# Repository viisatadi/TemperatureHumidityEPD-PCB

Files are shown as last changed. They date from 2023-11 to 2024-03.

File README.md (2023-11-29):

Temperature/Humidity ePaper Display KiCad Files
===============================================
  
This project is an attempt to port Kevin Kessler's Hackaday project from an STM32L0 MCU to one from Analog Devices. The purpose of this project was to investigate the effort required to switch micros.

From the original repo:
In order to investigate the low power modes and techniques for an STM32L0 class microprocessor, I've build a temperature and humidity display using an STM32L031F6 uC, an SI7021 I2C temperature/humidity sensor, and a Waveshare 1.54 inch black, white, and red ePaperDisplay. Starting with a straight-forward, non-optimized version of the software, this project will investigate and document the various power savings techniques that can be applied to the system, in order to get the power usage of the device down to a level that (hopefully) makes it practical to run off of a CR2032 coin cell. 

Track the progress on [Hackaday.io](https://hackaday.io/project/134018-coin-cell-powered-temperaturehumidity-display)

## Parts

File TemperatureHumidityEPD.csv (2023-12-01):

Reference | Value | Footprint | Datasheet | Description | Part Number | Qty
BT1 | CR2032 | Connectors_Custom:BatteryHolder_TE_BATT-HLD-000_1x2032 | ~ |  | BAT-HLD-001 | 1
C1, C10, C11, C14-C20 | 10u | Capacitor_SMD:C_0603_1608Metric_Pad1.08x0.95mm_HandSolder |  | capacitor, 10u, 10%, 10V, ceramic, X7T, SMT, 0603 (1608) | GRM188D71A106KA73J | 10
C2, C4, C5, C13 | 1u | Capacitor_SMD:C_0603_1608Metric_Pad1.08x0.95mm_HandSolder | ~ | capacitor, 1u, 10%, 10V, ceramic, X7R, SMT, 0603 (1608) | C1608X7R1A105K080AC | 4
C3 | 100n | Capacitor_SMD:C_0603_1608Metric_Pad1.08x0.95mm_HandSolder |  | capacitor, 0.1u, 5%, 16V, ceramic, X7R, SMT, 0603 (1608) | C0603C104K3RACTU | 1
C6, C8 | 22u | Capacitor_SMD:C_1206_3216Metric_Pad1.33x1.80mm_HandSolder |  | capacitor, 22u, 10%, 6.3V, ceramic, X7R, SMT, 1206 | GRM31CR70J226KE19L | 2
C7 | 22p | Capacitor_SMD:C_0603_1608Metric_Pad1.08x0.95mm_HandSolder |  | capacitor, 22p, 5%, 50V, ceramic, C0G, SMT, 0603 (1608) | CC0603JRNPO9BN220 | 1
C9, C12 | 4.7u | Capacitor_SMD:C_0805_2012Metric_Pad1.18x1.45mm_HandSolder |  | capacitor, 4.7u, 10%, 25V, ceramic, X7S, SMT, 0805 (2012) | GRM21BC71E475KE11L | 2
D1, D2 | LED | LED_SMD:LED_0805_2012Metric_Pad1.15x1.40mm_HandSolder | https://www.mouser.com/datasheet/2/180/IN_S85AT_Series_V1_1-2323391.pdf | LED, white, SMT, 0805 (2012) | IN-S85AT5UW | 2
D3-D5 | MBR0530 | Diode_SMD:D_SOD-123 | http://www.mccsemi.com/up_pdf/MBR0520~MBR0580(SOD123).pdf | diode, Schottky, 30Vr, 0.5A, SMT, SOD-123-3 | MBR0530T1G | 3
J1 | Conn_01x02 | Connectors_Custom:Pin_Header_Straight_1x02_Pitch2.54mm |  |  |  | 1
J2 | FTSH-105-01-L-DV-K | Connectors_Custom:SAMTEC_FTSH-105-01-L-DV-K | https://suddendocs.samtec.com/prints/ftsh-1xx-xx-xxx-dv-xxx-xxx-x-xx-mkt.pdf | connector, 10-pin, 2x5, 0.5mm pitch, polarized, SMT | FTSH-105-01-L-DV-K | 1
J3 | Conn_01x08 | Connector_JST:JST_PH_S8B-PH-SM4-TB_1x08-1MP_P2.00mm_Horizontal | https://www.jst-mfg.com/product/pdf/eng/ePH.pdf |  |  | 1
J4 | Conn_01x24 | Connectors_Custom:TE_2-1734839-4_1x24-1MP_P0.5mm_Horizontal_reversednumber | https://www.mouser.com/datasheet/2/418/7/ENG_CD_1734839_C_C_1734839-2017341.pdf | connector, FPC, 24 pin, 0.5mm pitch, top contact | 2-1734839-4 | 1
L1, L3 | 0 | Resistor_SMD:R_0603_1608Metric_Pad0.98x0.95mm_HandSolder |  | resistor, 0, 0.25W, thick film, SMT, 0603 (1608) | RCS06030000Z0EC | 2
L2 | 1u | Inductors_Custom:L_0805_2016Metric | https://product.tdk.com/system/files/dam/doc/product/inductor/inductor/smd/catalog/inductor_commercial_power_mlp2016_en.pdf | inductor, 1u, 20%, 1A, 117mohm, SMD, 0806 (2016) | MLP2016S1R0MT0S1 | 1
L4 | 68u | Inductors_Custom:L_3x3_H3 | https://www.bourns.com/pdfs/SDR0302.pdf | inductor, 68u, 10%, 300mA, 1.85ohm, SMT, 3mm_diam x 2mm | SDR0302-680KL | 1
MP1-MP4 | MOUNTHOLE | Connectors_Custom:TH-M3 |  |  |  | 4
Q1 | Si1308EDL | Package_TO_SOT_SMD:SOT-323_SC-70 | https://www.vishay.com/doc?63399 | mosfet, n-ch, 30V, 1.5A, 132mohm, 600mVth, SOT-323-3 (SC-70) | Si1308EDL-T1-GE3 | 1
Q2 | IRLML6344 | Package_TO_SOT_SMD:SOT-23-3 |  | mosfet, n-ch, 30Vds, 5A, 29mohm, 800mVth, SOT-23-3 | IRLML6344TRPBF | 1
R1-R5, R15, R19 | 10K | Resistor_SMD:R_0603_1608Metric_Pad0.98x0.95mm_HandSolder |  | resistor, 10k, 0.1W, thin film, 1%, 50ppm, SMT, 0603 (1603) | RT0603FRE0710KL | 7
R6, R7 | 1k | Resistor_SMD:R_0603_1608Metric_Pad0.98x0.95mm_HandSolder |  | resistor, 1k, 0.1W, thin film, 1%, 50ppm, SMT, 0603 (1608) | RT0603FRE131KL | 2
R8, R16 | 100R | Resistor_SMD:R_0603_1608Metric_Pad0.98x0.95mm_HandSolder |  | resistor, 100, 0.1W, thin film, 1%, 50ppm, SMT, 0603 (1603) | RT0603FRE07100RL | 2
R9, R10, R14 | 0 | Resistor_SMD:R_0603_1608Metric_Pad0.98x0.95mm_HandSolder |  | resistor, 0, 0.25W, thick film, SMT, 0603 (1608) | RCS06030000Z0EC | 3
R11, R12 | 56 | Resistor_SMD:R_0603_1608Metric_Pad0.98x0.95mm_HandSolder |  | resistor, 56, 0.1W, thick film, 1%, SMT, 0603 (1608) | RC0603FR-0756RL | 2
R13 | DNP | Resistor_SMD:R_0603_1608Metric_Pad0.98x0.95mm_HandSolder |  | resistor, 0, 0.25W, thick film, SMT, 0603 (1608) | RCS06030000Z0EC | 1
R17 | 100K | Resistor_SMD:R_0603_1608Metric_Pad0.98x0.95mm_HandSolder |  | resistor, 100k, 0.1W, thin film, 1%, 50ppm, SMT, 0603 (1603) | RT0603FRE07100KL | 1
R18 | 0R47 | Resistor_SMD:R_0805_2012Metric_Pad1.20x1.40mm_HandSolder |  | resistor, 0.47, 0.25W, thin film, 5%, 300ppm, SMT, 0805 (2012) | 2-2176054-4 | 1
SW1 | SW_Push | Switch_Custom:Panasonic_EVQPUJ_EVQPUA | ~ | switch, momentary-off, SMT | EVQ-P7A01P | 1
TP1, TP2 | TestPoint_2Pole | Connectors_Custom:TestPoint_Padx2_D2.0mm |  |  |  | 2
U1 | SI7021 | Silabs_custom:SI7021 | https://www.silabs.com/documents/public/data-sheets/Si7021-A20.pdf | IC, temperature and humidity sensor, SMT, DFN6_3x3 | SI7021-A20-GM1 | 1
U2 | MAX32660GTP | Package_DFN_QFN:TQFN-20-1EP_4x4mm_P0.5mm_EP2.7x2.7mm | https://www.analog.com/media/en/technical-documentation/data-sheets/max32660.pdf | IC, microcontroller, SMT, TQFN-EP-20 | MAX32660GTP | 1
U3 | MAX20343H | ADI_Power:MAX20343H | https://www.analog.com/media/en/technical-documentation/data-sheets/MAX20343-MAX20344.pdf | power regulator, buck-boost, 1.9V-5.5Vin, 3.5W, SMT, FC2QFN-12 | MAX20343HEFC+ | 1
Y1 | 32.7680KHZ | Crystal:Crystal_SMD_MicroCrystal_CM9V-T1A-2Pin_1.6x1.0mm_HandSoldering | ~ | crystal, 32.7680KHZ, 6PF, +/-20PPM, SMT, 1.6mm x 1.0mm | CM1610H32768DZB | 1

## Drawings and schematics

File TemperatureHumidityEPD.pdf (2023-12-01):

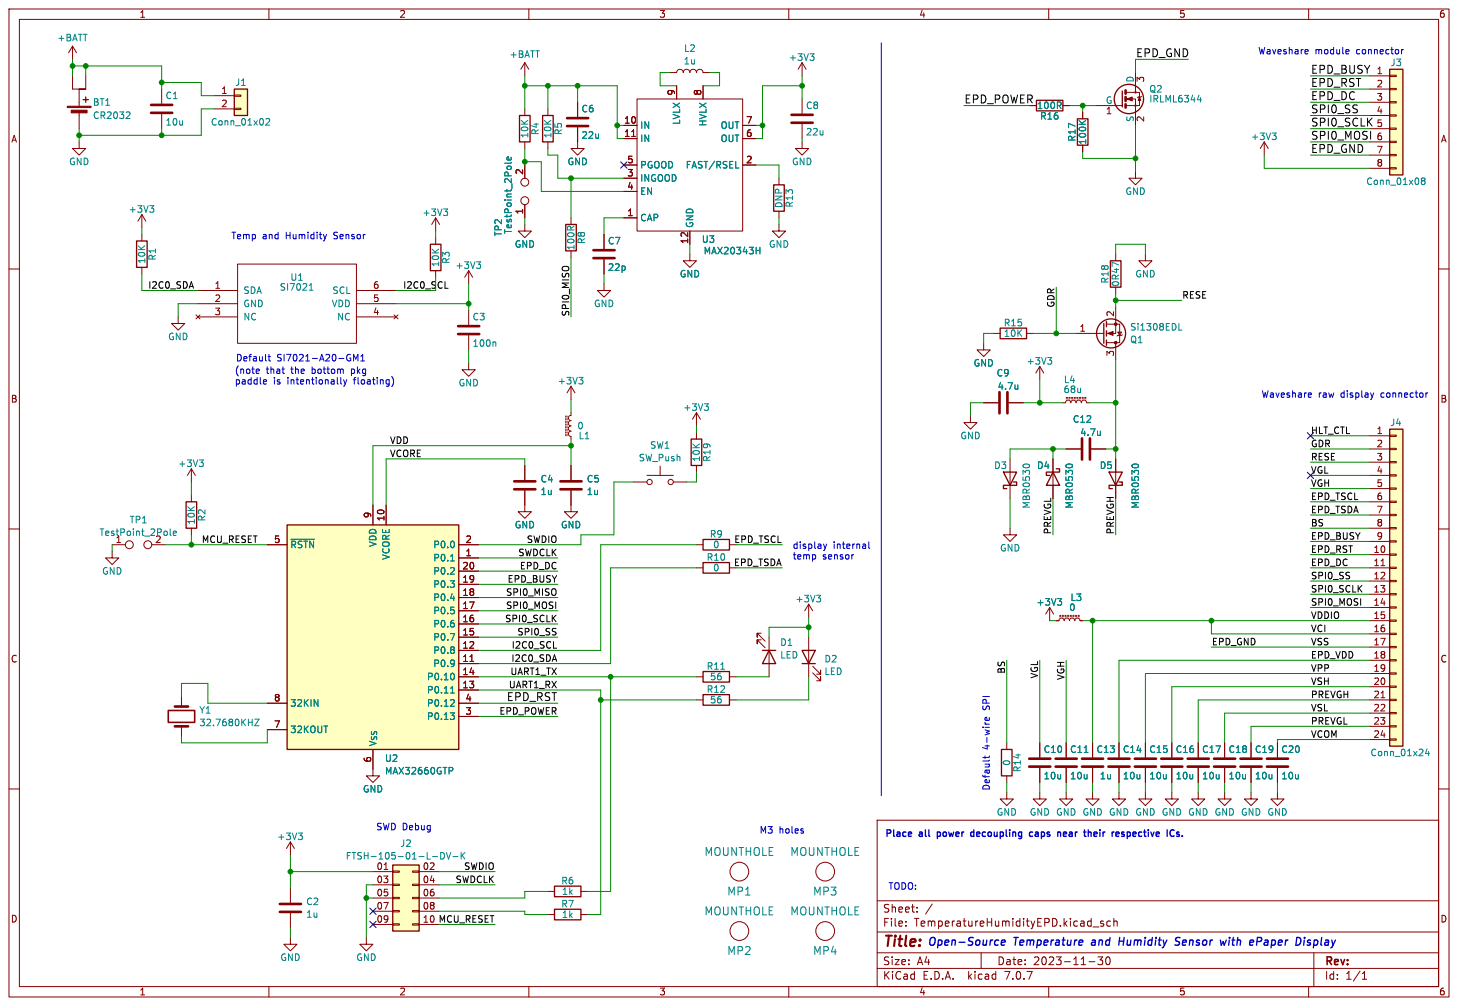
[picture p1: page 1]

(note that the bottom pkg

Id: 1/1 Title: File: TemperatureHumidityEPD.kicad_sch Sheet: /

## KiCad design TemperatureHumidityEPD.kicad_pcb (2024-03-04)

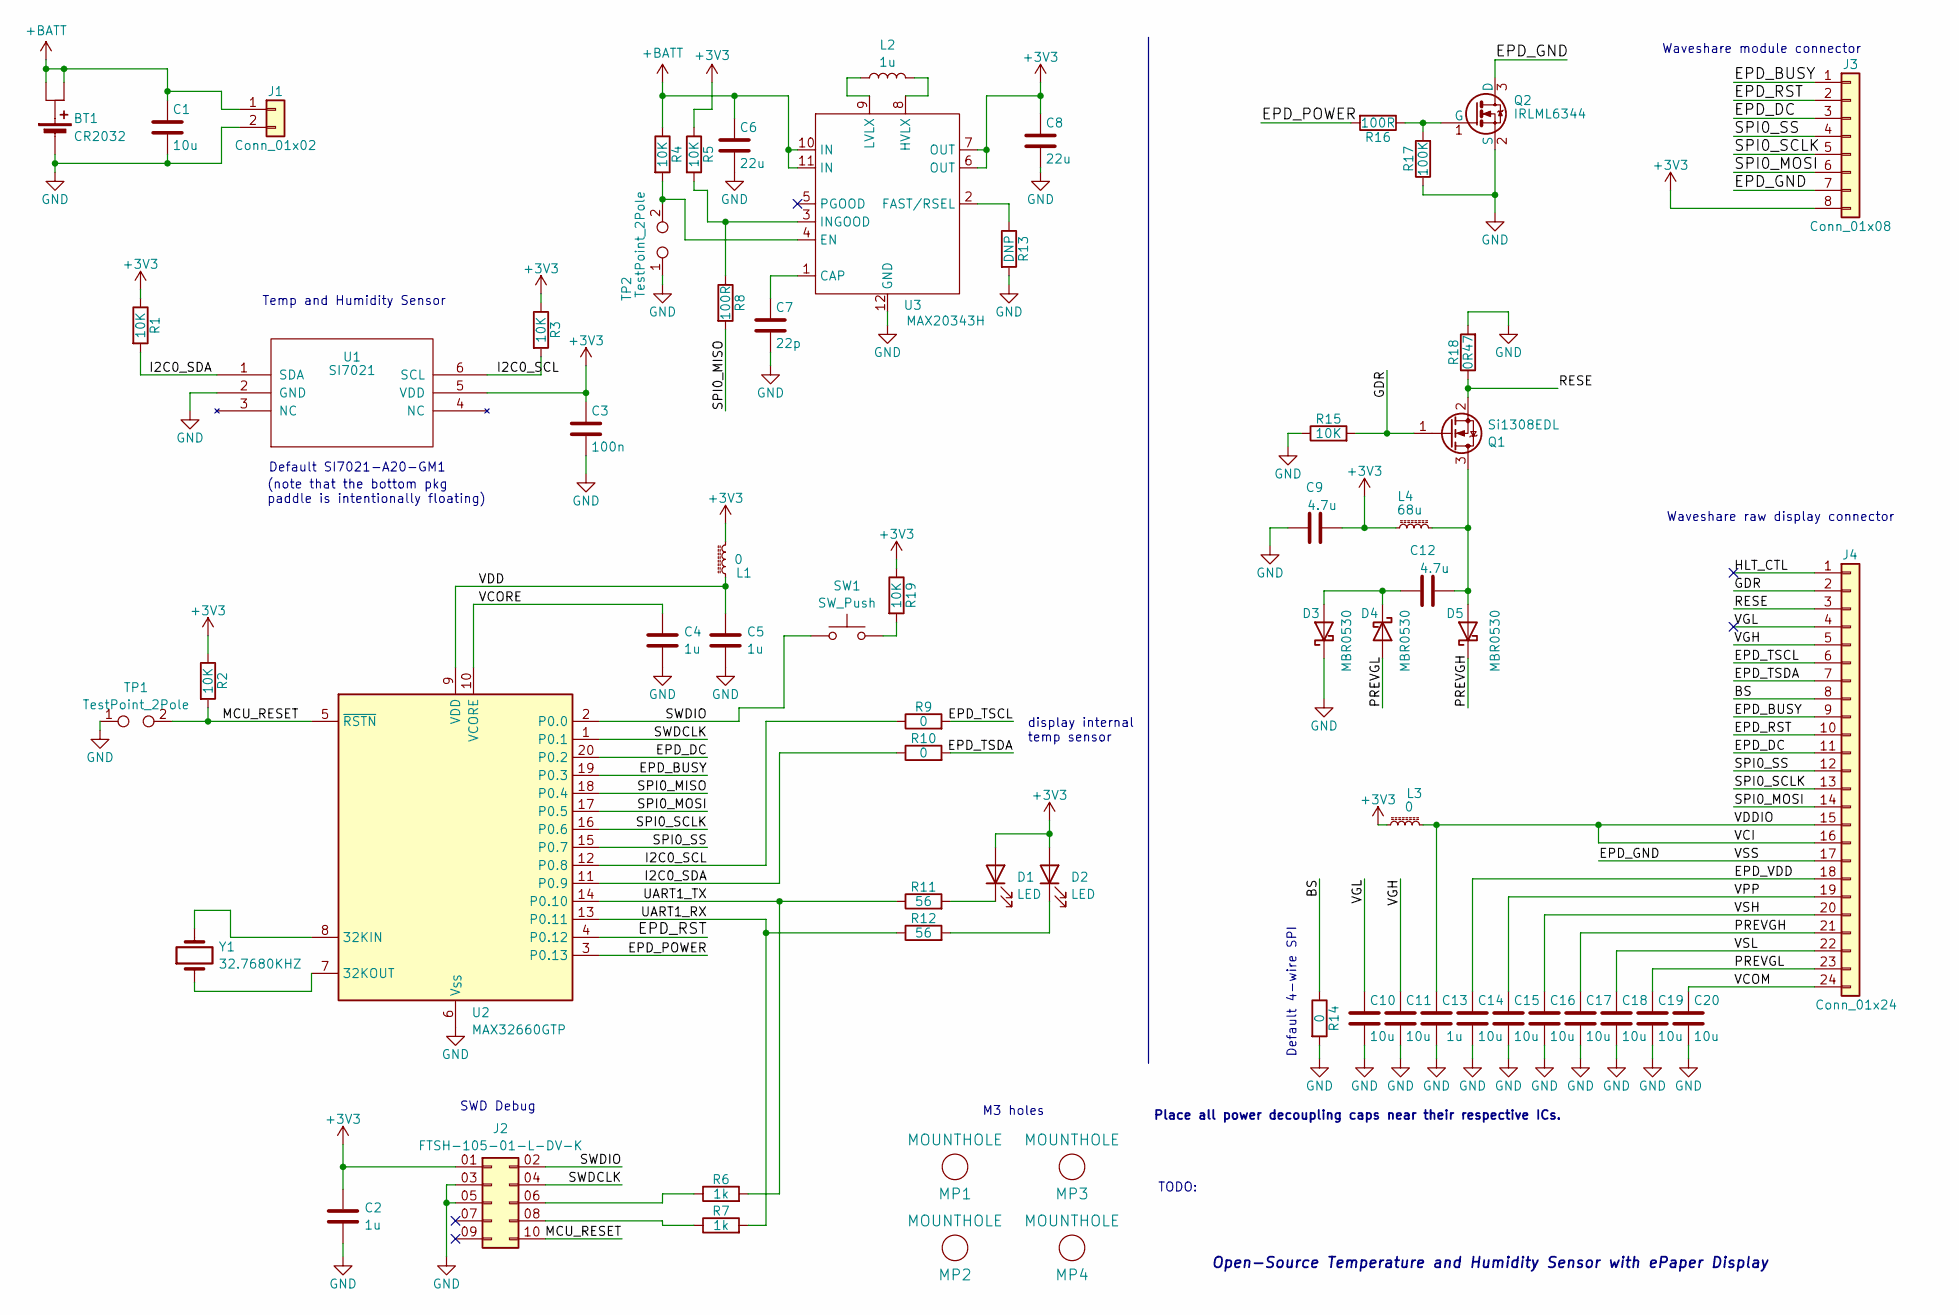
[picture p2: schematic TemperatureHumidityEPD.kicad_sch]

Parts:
BT1: CR2032; BatteryHolder_TE_BATT-HLD-000_1x2032; Part Number BAT-HLD-001
C1, C10, C11, C14, C15, C16, C17, C18, C19, C20: 10u; C_0603_1608Metric_Pad1.08x0.95mm_HandSolder; Part Number GRM188D71A106KA73J
C2, C4, C5, C13: 1u; C_0603_1608Metric_Pad1.08x0.95mm_HandSolder; Part Number C1608X7R1A105K080AC
C3: 100n; C_0603_1608Metric_Pad1.08x0.95mm_HandSolder; Part Number C0603C104K3RACTU
C6, C8: 22u; C_1206_3216Metric_Pad1.33x1.80mm_HandSolder; Part Number GRM31CR70J226KE19L
C7: 22p; C_0603_1608Metric_Pad1.08x0.95mm_HandSolder; Part Number CC0603JRNPO9BN220
C9, C12: 4.7u; C_0805_2012Metric_Pad1.18x1.45mm_HandSolder; Part Number GRM21BC71E475KE11L
D1, D2: LED; LED_0805_2012Metric_Pad1.15x1.40mm_HandSolder; Part Number IN-S85AT5UW
D3, D4, D5: MBR0530; D_SOD-123; Part Number MBR0530T1G
J1: Conn_01x02; Pin_Header_Straight_1x02_Pitch2.54mm
J2: FTSH-105-01-L-DV-K; SAMTEC_FTSH-105-01-L-DV-K; Part Number FTSH-105-01-L-DV-K
J3: Conn_01x08; JST_PH_S8B-PH-SM4-TB_1x08-1MP_P2.00mm_Horizontal
J4: Conn_01x24; TE_2-1734839-4_1x24-1MP_P0.5mm_Horizontal_reversednumber; Part Number 2-1734839-4
L1, L3: 0; R_0603_1608Metric_Pad0.98x0.95mm_HandSolder; Part Number RCS06030000Z0EC
L2: 1u; L_0805_2016Metric; Part Number MLP2016S1R0MT0S1
L4: 68u; L_3x3_H3; Part Number SDR0302-680KL
MP1, MP2, MP3, MP4: MOUNTHOLE; TH-M3
Q1: Si1308EDL; SOT-323_SC-70; Part Number Si1308EDL-T1-GE3
Q2: IRLML6344; SOT-23-3; Part Number IRLML6344TRPBF
R1, R2, R3, R4, R5, R15, R19: 10K; R_0603_1608Metric_Pad0.98x0.95mm_HandSolder; Part Number RT0603FRE0710KL
R6, R7: 1k; R_0603_1608Metric_Pad0.98x0.95mm_HandSolder; Part Number RT0603FRE131KL
R8, R16: 100R; R_0603_1608Metric_Pad0.98x0.95mm_HandSolder; Part Number RT0603FRE07100RL
R9, R10, R14: 0; R_0603_1608Metric_Pad0.98x0.95mm_HandSolder; Part Number RCS06030000Z0EC
R11, R12: 56; R_0603_1608Metric_Pad0.98x0.95mm_HandSolder; Part Number RC0603FR-0756RL
R13: DNP; R_0603_1608Metric_Pad0.98x0.95mm_HandSolder; Part Number RCS06030000Z0EC
R17: 100K; R_0603_1608Metric_Pad0.98x0.95mm_HandSolder; Part Number RT0603FRE07100KL
R18: 0R47; R_0805_2012Metric_Pad1.20x1.40mm_HandSolder; Part Number 2-2176054-4
SW1: SW_Push; Panasonic_EVQPUJ_EVQPUA; Part Number EVQ-P7A01P
TP1, TP2: TestPoint_2Pole; TestPoint_Padx2_D2.0mm
U1: SI7021; Part Number SI7021-A20-GM1
U2: MAX32660GTP; TQFN-20-1EP_4x4mm_P0.5mm_EP2.7x2.7mm; Part Number MAX32660GTP
U3: MAX20343H; Part Number MAX20343HEFC+
Y1: 32.7680KHZ; Crystal_SMD_MicroCrystal_CM9V-T1A-2Pin_1.6x1.0mm_HandSolder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; Part Number CM1610H32768DZB

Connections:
+3V3: C2.1, C3.1, C8.1, C9.2, D1.2 (A), D2.2 (A), J2.01 (Pin_1), J3.8, L1.2, L3.1, L4.1, R1.1, R2.1, R3.1, R5.1, R19.1, U1.5 (VDD), U3.6 (OUT), U3.7 (OUT)
+BATT: BT1.1 (+), BT1.2 (+), C1.1, C6.1, J1.1, R4.1, U3.10 (IN), U3.11 (IN)
/BS: J4.8, R14.1
/EPD_BUSY: J3.1, J4.9, U2.19 (P0.3)
/EPD_DC: J3.3, J4.11, U2.20 (P0.2)
/EPD_GND: J3.7, J4.17, Q2.3 (D)
/EPD_POWER: R16.2, U2.3 (P0.13)
/EPD_RST: J3.2, J4.10, U2.4 (P0.12)
/EPD_TSCL: J4.6, R9.2
/EPD_TSDA: J4.7, R10.2
/EPD_VDD: C14.1, J4.18
/GDR: J4.2, Q1.1 (G), R15.2
/HLT_CTL: J4.1
/I2C0_SCL: R3.2, R9.1, U1.6 (SCL), U2.12 (P0.8)
/I2C0_SDA: R1.2, R10.1, U1.1 (SDA), U2.11 (P0.9)
/MCU_RESET: J2.10, R2.2, TP1.2, U2.5 (~RSTN)
/PREVGH: C17.1, D5.1 (K), J4.21
/PREVGL: C19.1, D4.2 (A), J4.23
/RESE: J4.3, Q1.2 (S), R18.1
/SPI0_MISO: R8.2, U2.18 (P0.4)
/SPI0_MOSI: J3.6, J4.14, U2.17 (P0.5)
/SPI0_SCLK: J3.5, J4.13, U2.16 (P0.6)
/SPI0_SS: J3.4, J4.12, U2.15 (P0.7)
/SWDCLK: J2.04 (Pin_4), U2.1 (P0.1)
/SWDIO: J2.02 (Pin_2), SW1.1, U2.2 (P0.0)
/UART1_RX: R7.2, R12.1, U2.13 (P0.11)
/UART1_TX: R6.2, R11.1, U2.14 (P0.10)
/VCI: C13.1, J4.15, J4.16, L3.2
/VCOM: C20.1, J4.24
/VCORE: C4.1, U2.10 (VCORE)
/VDD: C5.1, L1.1, U2.9 (VDD)
/VGH: C11.1, J4.5
/VGL: C10.1, J4.4
/VPP: C15.1, J4.19
/VSH: C16.1, J4.20
/VSL: C18.1, J4.22
GND: BT1.3 (-), C1.2, C2.2, C3.2, C4.2, C5.2, C6.2, C7.2, C8.2, C9.1, C10.2, C11.2, C13.2, C14.2, C15.2, C16.2, C17.2, C18.2, C19.2, C20.2, D3.1 (K), J1.2, J2.03 (Pin_3), J2.05 (Pin_5), Q2.2 (S), R13.2, R14.2, R15.1, R17.1, R18.2, TP1.1, TP2.1, U1.2 (GND), U2.6 (V_{SS}), U2.21 (V_{SS}), U3.12 (GND)
unnamed: D1.1 (K), R11.2
unnamed: D2.1 (K), R12.2
unnamed: C12.1, D3.2 (A), D4.1 (K)
unnamed: C12.2, D5.2 (A), L4.2, Q1.3 (D)
unnamed: J2.06 (Pin_6), R6.1
unnamed: J2.08 (Pin_8), R7.1
unnamed: Q2.1 (G), R16.1, R17.2
unnamed: R19.2, SW1.2
unnamed: U2.8 (32KIN), Y1.2
unnamed: U2.7 (32KOUT), Y1.1
unnamed: C7.1, U3.1 (CAP)
unnamed: R4.2, TP2.2, U3.4 (EN)
unnamed: R13.1, U3.2 (FAST/RSEL)
unnamed: L2.2, U3.8 (HVLX)
unnamed: R5.2, R8.1, U3.3 (INGOOD)
unnamed: L2.1, U3.9 (LVLX)

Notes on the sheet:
Default 4-wire SPI
(note that the bottom pkg paddle is intentionally floating)
Open-Source Temperature and Humidity Sensor with ePaper Display
Place all power decoupling caps near their respective ICs.
display internal temp sensor
Temp and Humidity Sensor
Waveshare module connector
TODO:
Waveshare raw display connector
M3 holes
SWD Debug
Default SI7021-A20-GM1

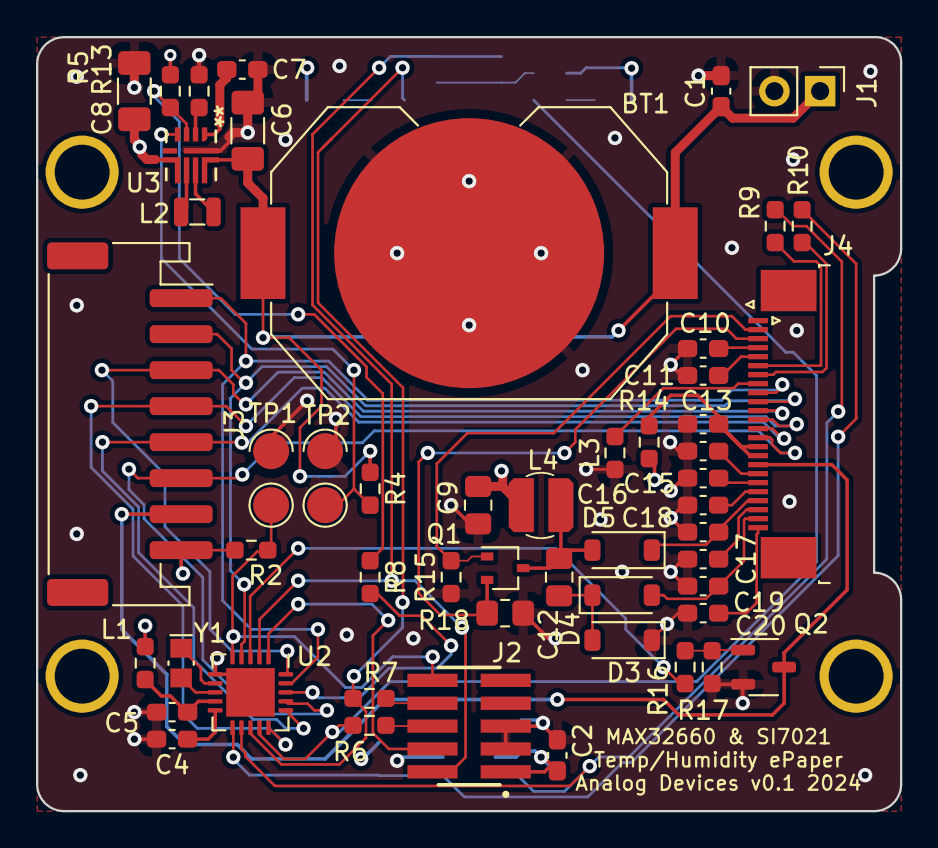
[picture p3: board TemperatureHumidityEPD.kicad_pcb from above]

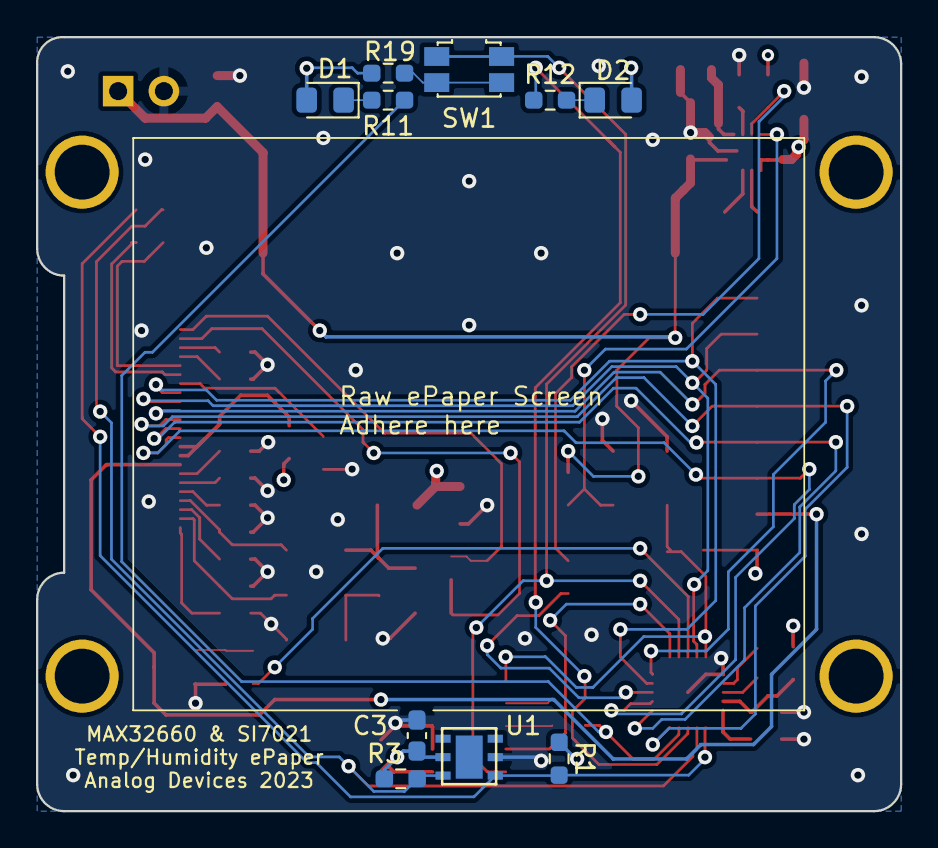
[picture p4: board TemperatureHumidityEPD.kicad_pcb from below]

Board: 4 copper layers, 48.0 x 43.0 mm, 66 parts (10 on the bottom side), 52 nets.

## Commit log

2023-11-29 Edits of the schematic, porting the design to MAX32660.
    Full part number information added in the schematic.
    Footprints linked. However, two parts need new footprints: 68uH inductor and the SWD debug connector.
    Related to this TODO: final check of the FPC connector.
    Group review of the schematic is now in progress.
    [TemperatureHumidityEPD.kicad_pcb, TemperatureHumidityEPD.kicad_sch]
2023-11-29 Added buck-boost for constant 3.3Vout.
    Fixes for ePaper display power.
    Double-check part availability.
    Final footprint reference changes in schematic.
    [TemperatureHumidityEPD.kicad_sch]
2023-12-01 Completely finished layout. Various small schematic tweaks along the way of layout.
    [TemperatureHumidityEPD-B.Cu.gbl, TemperatureHumidityEPD-B.Mask.gbs, TemperatureHumidityEPD-B.SilkS.gbo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]
2023-12-01 Fix schematic date, update PDF
    [TemperatureHumidityEPD.kicad_sch]
2023-12-01 Fix backside silkscreen. Added outline of raw display. Regenerated fab files.
    [TemperatureHumidityEPD-B_Cu.gbl, TemperatureHumidityEPD-B_Paste.gbp, TemperatureHumidityEPD-B_Silkscreen.gbo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]
2023-12-01 Fix Part Number for 1k resistor
    [TemperatureHumidityEPD.csv, TemperatureHumidityEPD.kicad_sch]
2024-03-04 Reversed D1 polarity in schematic and PCB. Moved INGOOD pull-up to 3V3 from input net +BATT. Update version and date.
    [TemperatureHumidityEPD-B_Cu.gbl, TemperatureHumidityEPD-B_Mask.gbs, TemperatureHumidityEPD-B_Paste.gbp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]
